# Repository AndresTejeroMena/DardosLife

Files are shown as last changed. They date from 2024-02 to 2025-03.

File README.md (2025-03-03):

# DardosLife
DardosLife is a personal project for recreational and learning purposes in which I have transformed a basic commercial electronic dartboard into one that, 
through an Arduino, is capable of sending information about where a dart has impacted to the computer. Using GODOT on the computer, I have programmed seven different games: 
501 series, cricket, battleship, connect4, burma road, ludo and football. 

Its use for commercial purposes is not permitted. 
The game concepts of battleship and connect4 are original creations, and the creator does not allow their commercial exploitation without consent. <br>
<p align="center">
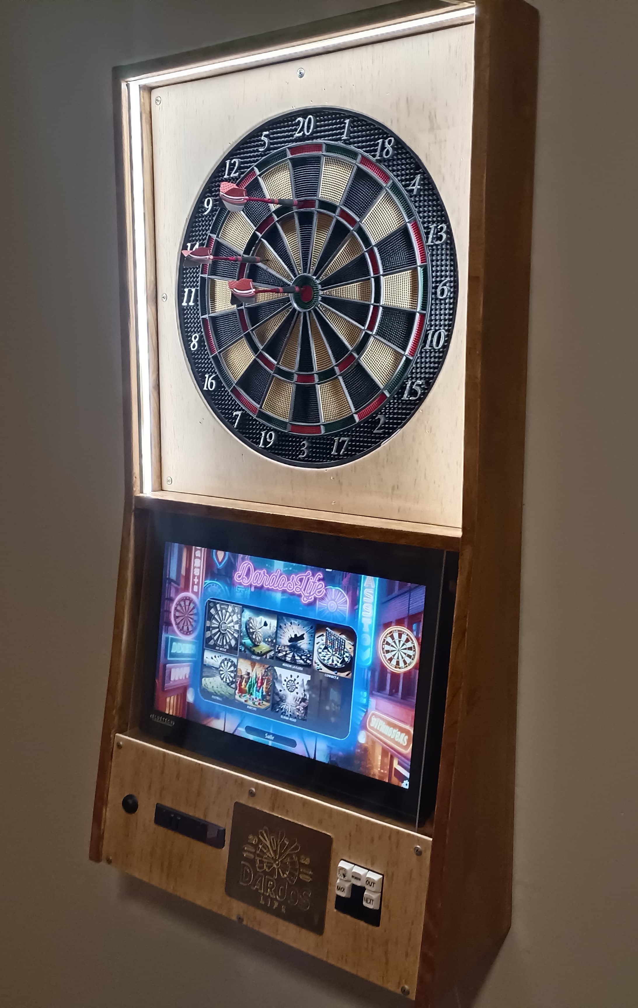
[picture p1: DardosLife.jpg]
Descripción de la imagen
  
</p>

<p align="center">
  Project developer: Andrés Tejero Mena (<a href="mailto:tejeromenaandres@gmail.com">tejeromenaandres@gmail.com</a>).
</p>

## How does it work?
https://youtu.be/JF_7bkpHpz4

To carry out this project, the first step was to understand how an electronic dartboard works on the inside. If you dismantle one, you'll see that the sensors consist of two sheets with circuits drawn on them, separated by an insulator. One sheet has 10 circuits and the other has 7, so when a dart hits the dartboard, one circuit makes contact with another, and we can determine where it has impacted.

Knowing this, I unsoldered the connectors of these sheets from the electronic board and used an Arduino to collect that information and output it through the serial port to the computer.
To do this, I designed a PCB with EAGLE and had it manufactured.

The Arduino program performs a loop of signal scanning through the 7-pin sheet and waits for the arrival of current through the 10-pin sheet. When one of those 10 pins detects the HIGH signal, it checks from which pin the signal was sent and to which pin it was received. Based on a predefined matrix, we know where the dart has impacted. All that's left is to send it via serial. Depending on the dartboard model, this matrix will vary, so I've created two different Arduino programs for two different dartboards.

At this point, we already have a dartboard capable of sending information to the computer. To program the games, I used GODOT, a very intuitive and easy-to-learn tool. In less than a month, I went from not knowing about GODOT's existence to having programmed 7 games. The only thing needed for it to work is to use a C# script to read the serial port and send that information to GODOT, where I programmed all the games in its GDScript language.

This has been a very enjoyable project that I wanted to share with you. The goal was always to challenge myself and learn; there were never any commercial purposes involved.
## What I've used:
Decathlon Canaveral ED110 electronic dartboard

Arduino Nano 33 Ble

Soldering iron

10 resistors of 10KOhm

Laptop

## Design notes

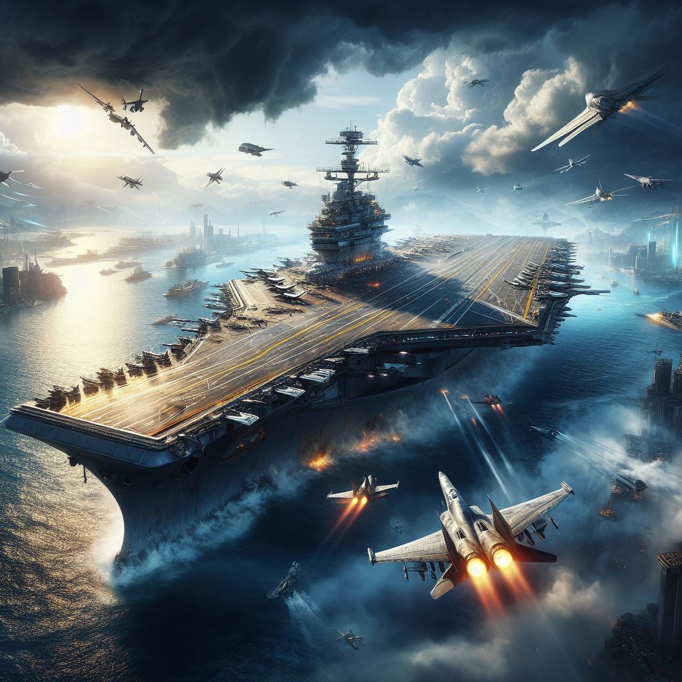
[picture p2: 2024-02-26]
image/HundirLaFlota/portaviones.jpg

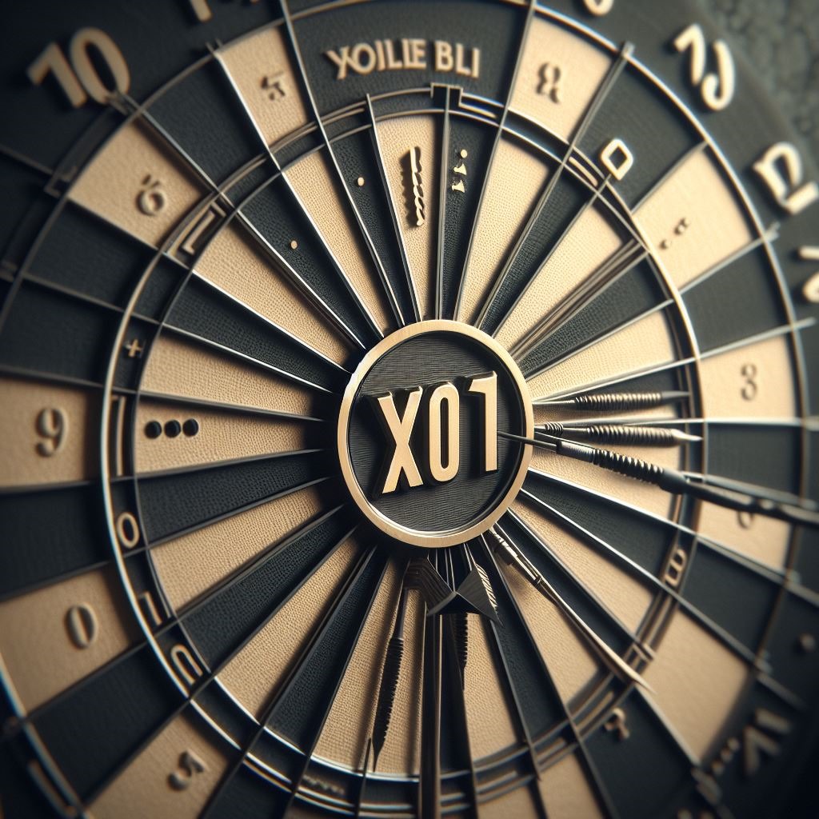
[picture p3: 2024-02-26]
image/ModosDeJuego/x01.jpg

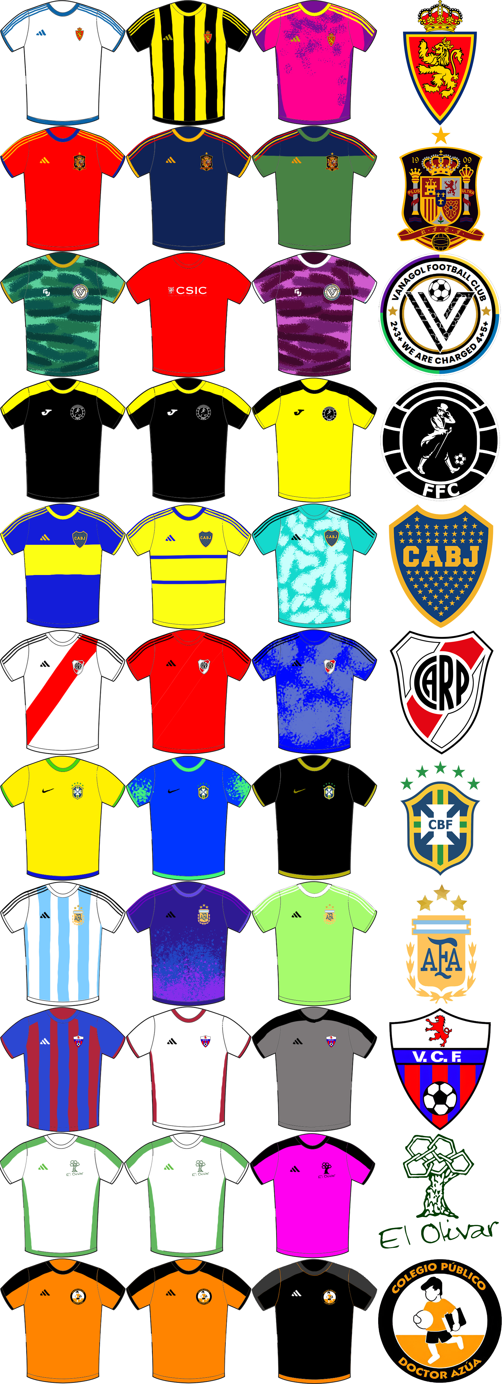
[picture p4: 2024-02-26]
image/Football/equipos.png

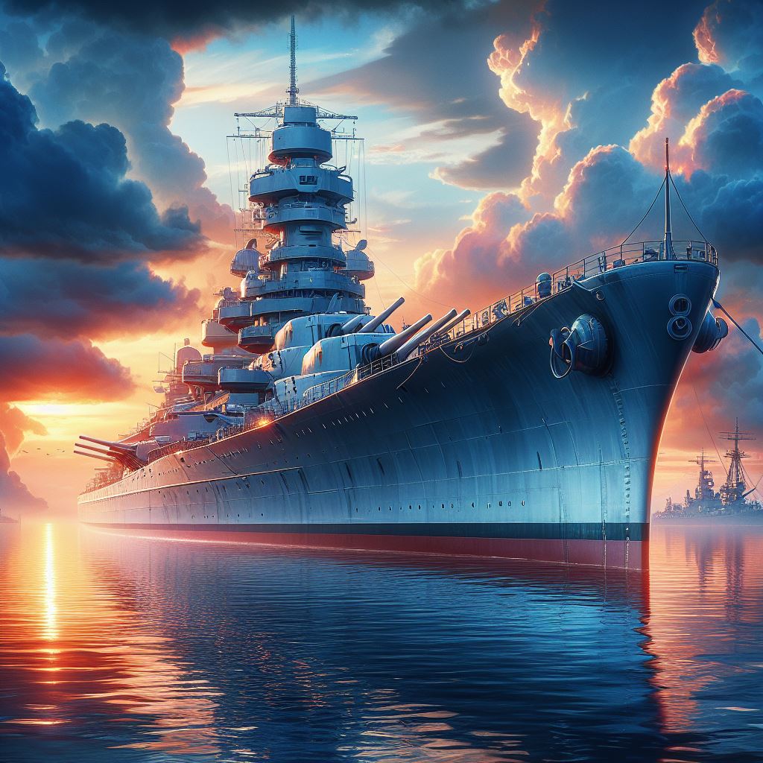
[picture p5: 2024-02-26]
image/HundirLaFlota/destructor.jpg

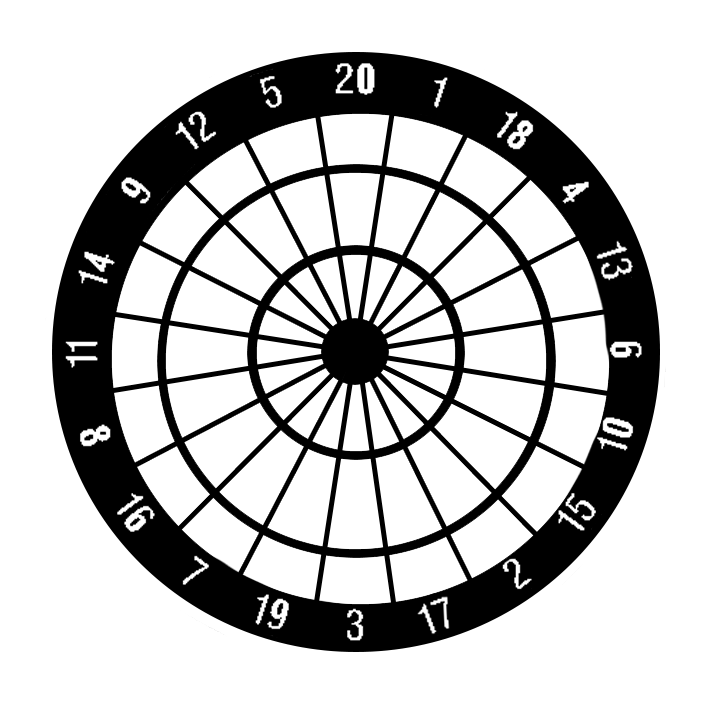
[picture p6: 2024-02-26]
image/HundirLaFlota/diana.png

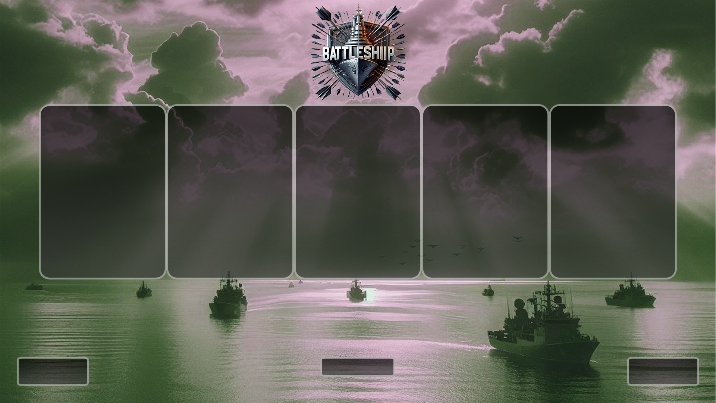
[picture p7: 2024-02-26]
image/Fondos/hundirlaflota_menu.png

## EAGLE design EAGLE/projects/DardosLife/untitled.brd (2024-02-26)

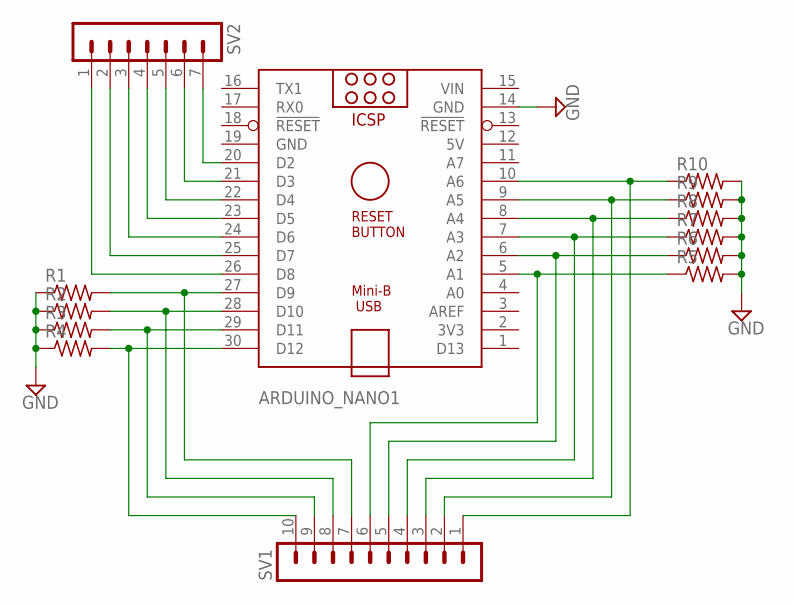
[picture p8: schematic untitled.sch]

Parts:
ARDUINO_NANO1: ARDUINO_NANO
R1, R2, R3, R4, R5, R6, R7, R8, R9, R10: R-US_0309/12; 0309/12
SV1: MA10-1
SV2: MA07-1

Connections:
5V: ARDUINO_NANO1.12 (5V)
GND: ARDUINO_NANO1.14 (GND), ARDUINO_NANO1.19 (GND), R1.1, R2.1, R3.1, R4.1, R5.2, R6.2, R7.2, R8.2, R9.2, R10.2
unnamed: ARDUINO_NANO1.30 (D12), R4.2, SV1.10
unnamed: ARDUINO_NANO1.29 (D11), R3.2, SV1.9
unnamed: ARDUINO_NANO1.28 (D10), R2.2, SV1.8
unnamed: ARDUINO_NANO1.27 (D9), R1.2, SV1.7
unnamed: ARDUINO_NANO1.5 (A1), R5.1, SV1.6
unnamed: ARDUINO_NANO1.6 (A2), R6.1, SV1.5
unnamed: ARDUINO_NANO1.7 (A3), R7.1, SV1.4
unnamed: ARDUINO_NANO1.8 (A4), R8.1, SV1.3
unnamed: ARDUINO_NANO1.9 (A5), R9.1, SV1.2
unnamed: ARDUINO_NANO1.10 (A6), R10.1, SV1.1
unnamed: ARDUINO_NANO1.26 (D8), SV2.1
unnamed: ARDUINO_NANO1.25 (D7), SV2.2
unnamed: ARDUINO_NANO1.24 (D6), SV2.3
unnamed: ARDUINO_NANO1.23 (D5), SV2.4
unnamed: ARDUINO_NANO1.22 (D4), SV2.5
unnamed: ARDUINO_NANO1.21 (D3), SV2.6
unnamed: ARDUINO_NANO1.20 (D2), SV2.7
VIN: ARDUINO_NANO1.15 (VIN)

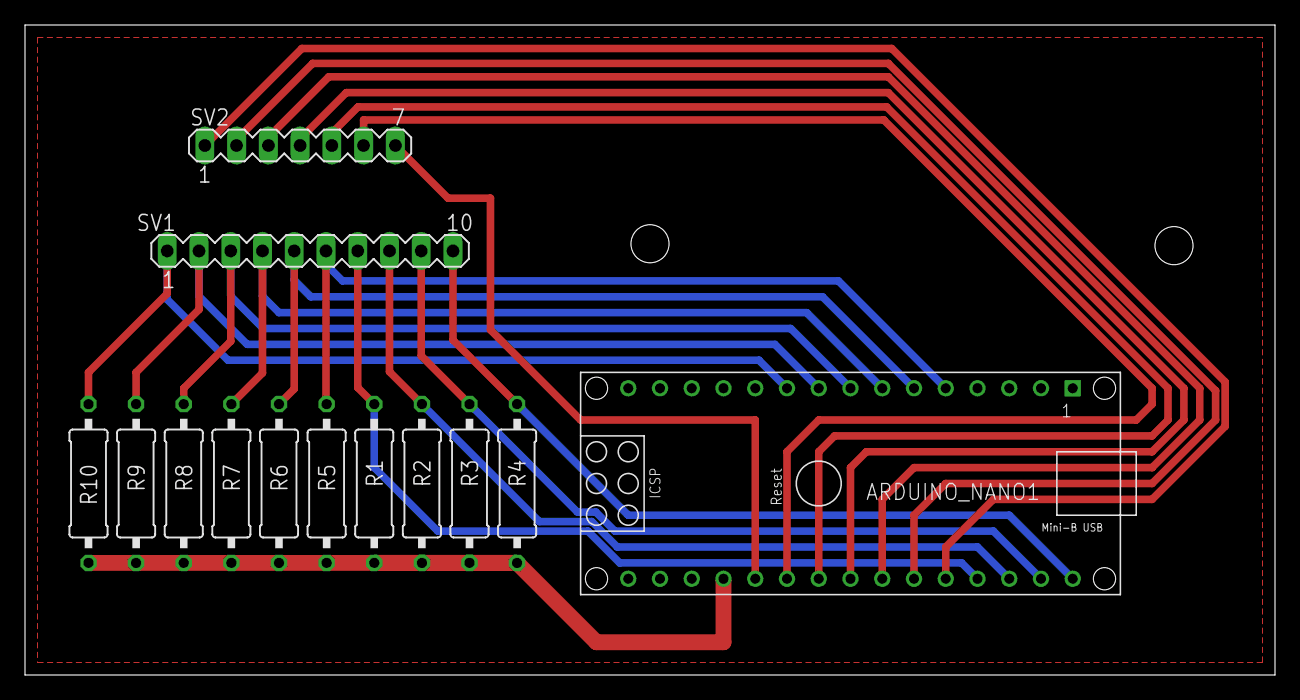
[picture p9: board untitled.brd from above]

Board: 2 copper layers, 100.0 x 52.0 mm, 13 parts (0 on the bottom side), 18 nets.

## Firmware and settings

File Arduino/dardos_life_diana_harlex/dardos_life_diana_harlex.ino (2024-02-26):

// Define los pines de salida digitales
const int salidaPinesDigitales[] = {2, 3, 4, 5, 6, 7, 8};  // Cambia según tus pines disponibles
const int numSalidaPinesDigitales = 7;

// Define los pines de entrada digitales
const int entradaPinesDigitales[] = {9, 10, 11, 12};  // Cambia según tus pines disponibles
const int numEntradaPinesDigitales = 4;

// Define los pines de entrada analógicos
const int entradaPinesAnalogicos[] = {A1, A2, A3, A4, A5, A6};  // Cambia según tus pines disponibles
const int numEntradaPinesAnalogicos = 6;

// Define el umbral para la detección analógica
const int umbral = 500;

// Define la estructura para representar cada celda de la matriz
struct CeldaDiana {
  int numero;
  char tipo;
};

// Define la matriz 7x10 para representar la disposición de la diana
CeldaDiana matrizDiana[7][10] = {
  {{2, 'T'}, {15, 'T'}, {10, 'T'}, {6, 'T'}, {17, 'T'}, {3, 'T'}, {13, 'T'}, {4, 'T'}, {18, 'T'}, {1, 'T'}},
  {{2, 'D'}, {15, 'D'}, {10, 'D'}, {6, 'D'}, {17, 'D'}, {3, 'D'}, {13, 'D'}, {4, 'D'}, {18, 'D'}, {1, 'D'}},
  {{2, 'S'}, {15, 'S'}, {10, 'S'}, {6, 'S'}, {17, 'S'}, {3, 'S'}, {13, 'S'}, {4, 'S'}, {18, 'S'}, {1, 'S'}},
  {{0, 'D'}, {0, 'S'}, {0, 'S'}, {0, 'S'}, {0, 'D'}, {0, 'S'}, {0, 'T'}, {0, 'S'}, {25, 'S'}, {25, 'D'}},
  {{16, 'S'}, {8, 'S'}, {11, 'S'}, {14, 'S'}, {7, 'S'}, {19, 'S'}, {9, 'S'}, {12, 'S'}, {5, 'S'}, {20, 'S'}},
  {{16, 'D'}, {8, 'D'}, {11, 'D'}, {14, 'D'}, {7, 'D'}, {19, 'D'}, {9, 'D'}, {12, 'D'}, {5, 'D'}, {20, 'D'}},
  {{16, 'T'}, {8, 'T'}, {11, 'T'}, {14, 'T'}, {7, 'T'}, {19, 'T'}, {9, 'T'}, {12, 'T'}, {5, 'T'}, {20, 'T'}}
};

// Variable para almacenar el tiempo de inicio del barrido
//unsigned long tiempoInicioBarrido = 0;

void setup() {
  Serial.begin(9600);  // Inicializa la comunicación serial
  while (!Serial);

  for (int i = 0; i < numSalidaPinesDigitales; ++i) {
    pinMode(salidaPinesDigitales[i], OUTPUT);
  }
}

void loop() {
  //tiempoInicioBarrido = micros(); // Guarda el tiempo de inicio del barrido
  for (int i = 0; i < numSalidaPinesDigitales; ++i) {
    digitalWrite(salidaPinesDigitales[i], HIGH);
    // Lee las entradas digitales
    for (int j = 0; j < numEntradaPinesDigitales; ++j) {
      int estadoDigital = digitalRead(entradaPinesDigitales[j]);

      // Si hay un contacto, imprime la información en el monitor serial
      if (estadoDigital == HIGH) {
        CeldaDiana celda = matrizDiana[i][j];
        Serial.print(celda.numero);
        Serial.print(":");
        Serial.println(celda.tipo);
        delay(500);
      }
    }
    // Lee las entradas analógicas
    for (int k = 0; k < numEntradaPinesAnalogicos; ++k) {
      int lecturaAnalogica = analogRead(entradaPinesAnalogicos[k]);

      // Si hay un contacto, imprime la información en el monitor serial
      if (lecturaAnalogica > umbral) {
        CeldaDiana celda = matrizDiana[i][k + numEntradaPinesDigitales];
        Serial.print(celda.numero);
        Serial.print(":");
        Serial.println(celda.tipo);
        delay(500);
      }
    }

    digitalWrite(salidaPinesDigitales[i], LOW);
  }
  //unsigned long duracionBarrido = micros() - tiempoInicioBarrido;
  //Serial.println(duracionBarrido);
}

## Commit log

2024-02-17 Subir Proyecto
    [copper_bottom.gbr, copper_top.gbr, drill_1_16.xln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]
2024-02-26 Publico Arduinos
    [copper_bottom.gbr, copper_top.gbr, drill_1_16.xln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]
2024-02-26 Publico Eagle
    [untitled.brd, untitled.sch]
2024-02-28 Ajuste TLDR para uso con ArduinoNano
2025-02-28 Actualiza la carpeta Escenas con nuevos contenidos
2025-02-28 Actualiza la carpeta Scripts con nuevas modificaciones
